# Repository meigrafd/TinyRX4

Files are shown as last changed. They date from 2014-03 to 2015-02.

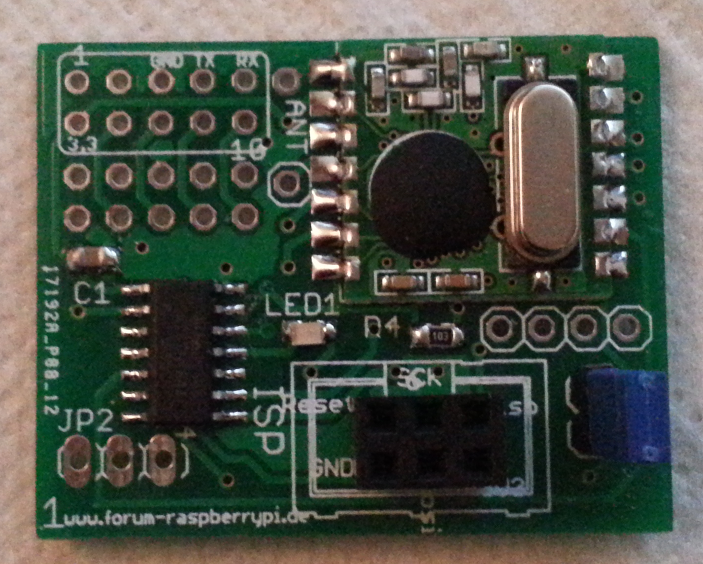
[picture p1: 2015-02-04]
TinyRX4_large.png

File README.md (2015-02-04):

TinyRX4
=======

RFM12B based TinyRX Receiver for RaspberryPI  

Projekt Page: http://www.forum-raspberrypi.de/Thread-messen-steuern-regeln-batteriebetriebene-funk-sensoren  

## Compiled Sketch size

#### with RFM12B lib:

Receive_PI.ino --> 5.730 Bytes  
Transceiver_PI.ino --> 8.184 Bytes (of 8.192 Bytes)  

#### with JeeLib:

Transceiver_PI_JeeLib.ino --> 7.850 Bytes

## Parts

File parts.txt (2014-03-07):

Partlist

Exported from Empfangsboard.brd at 17.02.2014 13:19:52

EAGLE Version 6.4.0 Copyright (c) 1988-2013 CadSoft

Assembly variant: 

Part     Value          Package  Library        Position (mm)         Orientation

ANT                     1,6/0,8  JeeLabs        (2.6 15.24)           R0
ATTINY84 TINY\84-SSU    SOIC14   avr-7          (13.97 7.62)          R0
C1       100n           C0805    rcl            (8 3.81)              R90
C2       100n           C0805    rcl            (13.97 26.67)         MR270
ISP                     ML6      con-harting-ml (20.32 20.32)         R270
JP1                     1X02     SparkFun       (19.05 30.48)         R180
JP3                     1X03     pinhead        (21.59 5.08)          R270
LED1                    SML0805  led            (20.32 11.43)         R180
R1       220            R0805    rcl            (21.59 13.97)         MR270
R3       10K            R0805    rcl            (16.51 26.67)         MR90
R4       10K            R0805    rcl            (8.89 26.67)          MR90
RASPI                   FE05-2   con-lsta       (3.81 7.62)           R90
RFM12B   RFM12B         RFM12B   JeeLabs        (7.7 26.67)           R270

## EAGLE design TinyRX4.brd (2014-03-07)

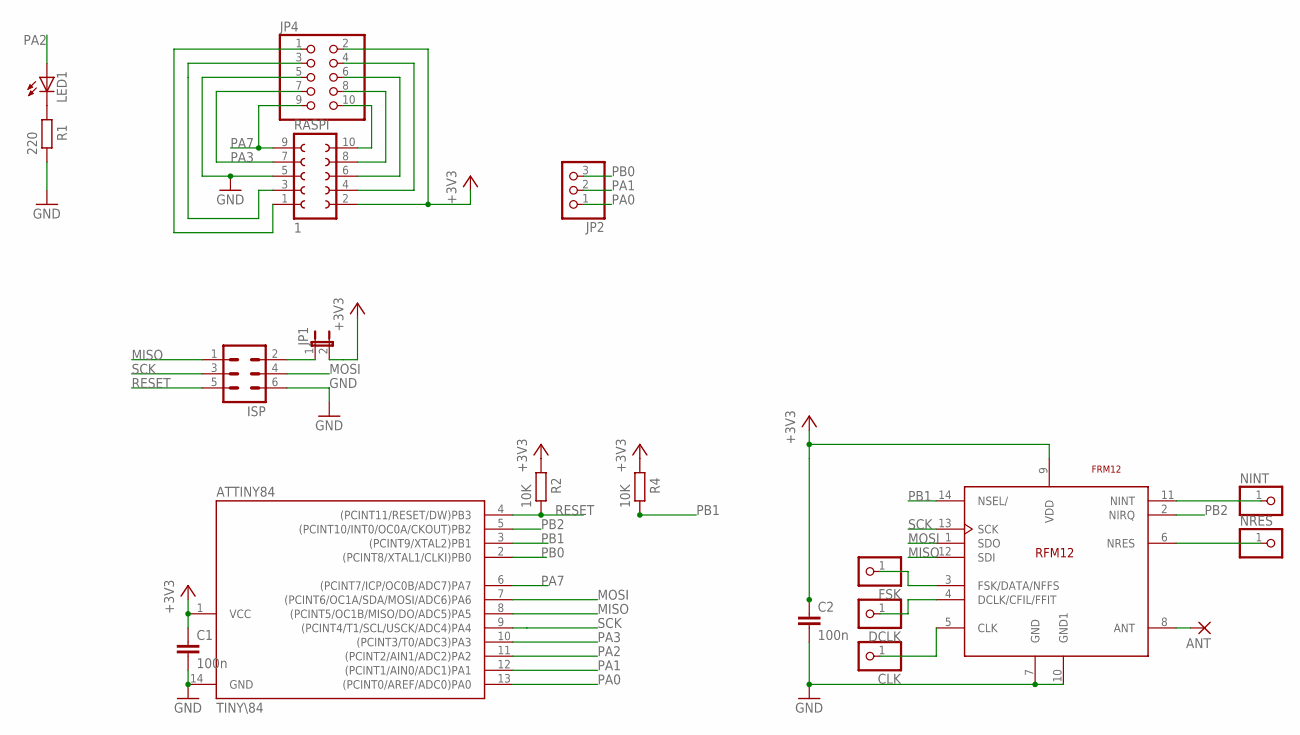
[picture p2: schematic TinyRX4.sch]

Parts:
ANT: 1,6/0,8
ATTINY84: TINY\84; SOIC14
C1, C2: 100n; C0805
CLK: PINHD-1X1; 1X01
DCLK: PINHD-1X1; 1X01
FSK: PINHD-1X1; 1X01
ISP: ML6
JP1: JUMPER-2PTH; 1X02
JP2: PINHD-1X3; 1X03
JP4: PINHD-2X5; 2X05
LED1: LEDSML0805; SML0805
NINT: PINHD-1X1; 1X01
NRES: PINHD-1X1; 1X01
R1: 220; R0805
R2, R4: 10K; R0805
RASPI: 1; FE05-2
U$1: FRM12; RFM12

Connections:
+3V3: ATTINY84.1 (VCC), C1.1, C2.1, JP1.2, JP4.2, R2.2, R4.2, RASPI.2, U$1.9 (VDD)
GND: ATTINY84.14 (GND), C1.2, C2.2, ISP.6, JP4.5, R1.1, RASPI.5, U$1.7 (GND), U$1.10 (GND1)
MISO: ATTINY84.8 ((PCINT5/OC1B/MISO/DO/ADC5)PA5), ISP.1, U$1.12 (SDI)
MOSI: ATTINY84.7 ((PCINT6/OC1A/SDA/MOSI/ADC6)PA6), ISP.4, U$1.1 (SDO)
unnamed: ISP.2, JP1.1
unnamed: JP4.10, RASPI.10
unnamed: LED1.C, R1.2
unnamed: JP4.8, RASPI.8
unnamed: JP4.6, RASPI.6
unnamed: ANT.1, U$1.8 (ANT)
unnamed: JP4.4, RASPI.4
unnamed: JP4.1, RASPI.1
unnamed: JP4.3, RASPI.3
unnamed: NINT.1, U$1.11 (NINT)
unnamed: CLK.1, U$1.5 (CLK)
unnamed: DCLK.1, U$1.4 (DCLK/CFIL/FFIT)
unnamed: NRES.1, U$1.6 (NRES)
unnamed: FSK.1, U$1.3 (FSK/DATA/NFFS)
PA0: ATTINY84.13 ((PCINT0/AREF/ADC0)PA0), JP2.1
PA1: ATTINY84.12 ((PCINT1/AIN0/ADC1)PA1), JP2.2
PA2: ATTINY84.11 ((PCINT2/AIN1/ADC2)PA2), LED1.A
PA3: ATTINY84.10 ((PCINT3/T0/ADC3)PA3), JP4.7, RASPI.7
PA7: ATTINY84.6 ((PCINT7/ICP/OC0B/ADC7)PA7), JP4.9, RASPI.9
PB0: ATTINY84.2 ((PCINT8/XTAL1/CLKI)PB0), JP2.3
PB1: ATTINY84.3 ((PCINT9/XTAL2)PB1), R4.1, U$1.14 (NSEL/)
PB2: ATTINY84.5 ((PCINT10/INT0/OC0A/CKOUT)PB2), U$1.2 (NIRQ)
RESET: ATTINY84.4 ((PCINT11/RESET/DW)PB3), ISP.5, R2.1
SCK: ATTINY84.9 ((PCINT4/T1/SCL/USCK/ADC4)PA4), ISP.3, U$1.13 (SCK)

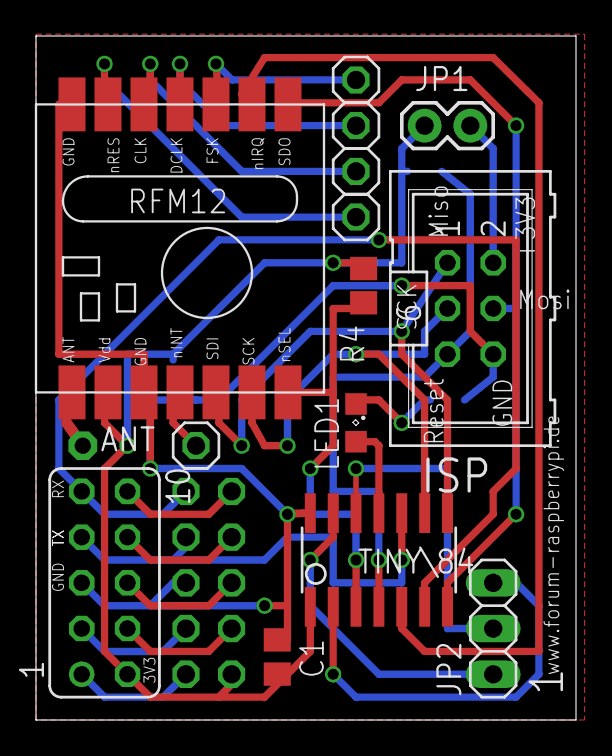
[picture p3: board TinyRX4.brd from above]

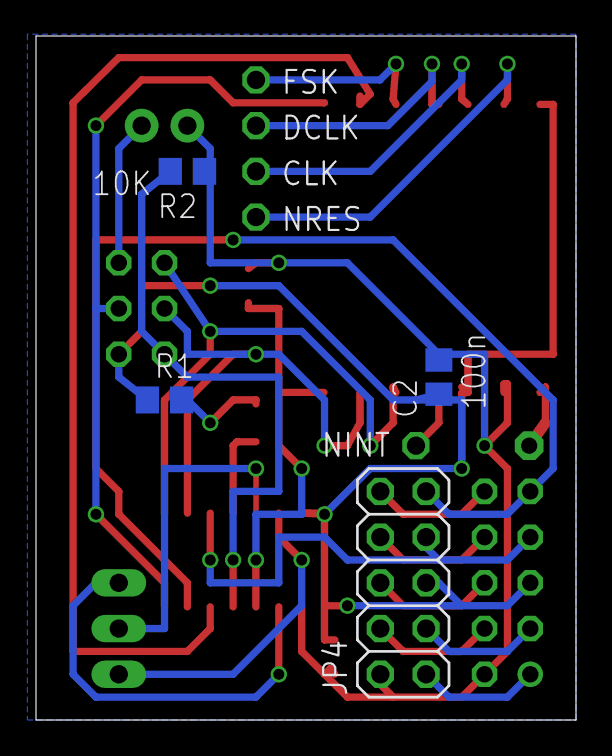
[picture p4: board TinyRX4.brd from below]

Board: 2 copper layers, 30.0 x 38.0 mm, 19 parts (4 on the bottom side), 28 nets.

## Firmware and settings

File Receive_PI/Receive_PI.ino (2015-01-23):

// RFM12B Receiver for RaspberryPI
//
// Basiert zum Teil auf der Arbeit von Nathan Chantrell
//
// modified by meigrafd @ 16.12.2013 - for UART on RaspberryPI
//------------------------------------------------------------------------------
#include <RFM12B.h>
#include <avr/sleep.h>
#include <SoftwareSerial.h>
//------------------------------------------------------------------------------
// You will need to initialize the radio by telling it what ID it has and what network it's on
// The NodeID takes values from 1-127, 0 is reserved for sending broadcast messages (send to all nodes)
// The Network ID takes values from 0-255
// By default the SPI-SS line used is D10 on Atmega328. You can change it by calling .SetCS(pin) where pin can be {8,9,10}
#define NODEID            22  //network ID used for this unit
#define NETWORKID        210  //the network ID we are on
#define ACK_TIME        2000  // # of ms to wait for an ack
#define SERIAL_BAUD     9600
//------------------------------------------------------------------------------
// PIN-Konfiguration 
//------------------------------------------------------------------------------
// UART pins
#define rxPin 7 // D7, PA3
#define txPin 3 // D3, PA7. pin der an RXD vom PI geht.
// LED pin
#define LEDpin 8 // D8, PA2 - set to 0 to disable LED
/*
                     +-\/-+
               VCC  1|    |14  GND
          (D0) PB0  2|    |13  AREF (D10)
          (D1) PB1  3|    |12  PA1 (D9)
             RESET  4|    |11  PA2 (D8)
INT0  PWM (D2) PB2  5|    |10  PA3 (D7)
      PWM (D3) PA7  6|    |9   PA4 (D6)
      PWM (D4) PA6  7|    |8   PA5 (D5) PWM
                     +----+
*/

//encryption is OPTIONAL
//to enable encryption you will need to:
// - provide a 16-byte encryption KEY (same on all nodes that talk encrypted)
// - to call .Encrypt(KEY) to start en
// - to stop encrypting call .Encrypt(NULL)
//#define KEY   "ABCDABCDABCDABCD"

// Initialise UART
SoftwareSerial mySerial(rxPin, txPin);

// Need an instance of the Radio Module
RFM12B radio;

//##############################################################################

static void activityLED (byte mode) {
  pinMode(LEDpin, OUTPUT);
  digitalWrite(LEDpin, mode);
}

// blink led
static void blink (byte pin, byte n = 3) {
  pinMode(pin, OUTPUT);
  for (byte i = 0; i < 2 * n; ++i) {
    delay(100);
    digitalWrite(pin, !digitalRead(pin));
  }
}

// init Setup
void setup() {
  pinMode(rxPin, INPUT);
  pinMode(txPin, OUTPUT);
  mySerial.begin(SERIAL_BAUD);
  radio.Initialize(NODEID, RF12_433MHZ, NETWORKID);
  #ifdef KEY
    radio.Encrypt((byte*)KEY);      //comment this out to disable encryption
  #endif
  if (LEDpin) {
    activityLED(1); // LED on
    delay(1000);
    activityLED(0); // LED off
  }
}

// Loop
void loop() {
  if (radio.ReceiveComplete()) {
    if (radio.CRCPass()) {
      //node ID of TX, extracted from RF datapacket. Not transmitted as part of structure
      mySerial.print(radio.GetSender(), DEC);
      mySerial.print(" ");
      int i;
      for (byte i = 0; i < *radio.DataLen; i++) //can also use radio.GetDataLen() if you don't like pointers
        mySerial.print((char) radio.Data[i]);

      if (LEDpin) {
        blink(LEDpin, 2);
      }
      if (radio.ACKRequested()) {
        radio.SendACK();
        mySerial.print(" - ACK sent");
      }
    } else {
      mySerial.print("BAD-CRC");
      if (LEDpin) {
        activityLED(1); // LED on
        delay(1000);
        activityLED(0); // LED off
      }
    }
    mySerial.println();
  }
}

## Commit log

2014-03-07 Public build
    [TinyRX4.brd, TinyRX4.sch]
2015-01-23 Added Sensor.pl and Receiver_PI.ino
2015-01-31 Added watchdog_Sensor.sh for Sensor.pl
